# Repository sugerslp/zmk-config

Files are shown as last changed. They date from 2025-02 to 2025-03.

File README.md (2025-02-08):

# キーボードについて
キーボード名：Title72  
[Teihai70H](https://blog.alglab.net/archives/teihai70h-buildguide/)にインスパイアされて設計したオリジナルキーボードです。

## 特徴
・ZMKによる無線接続対応  
・60%日本語/英語配列  
・Choc v2スイッチを採用した薄い構造

## 販売
たぶん[booth](https://te9no.booth.pm/)で販売  

## ビルドガイド
[here](https://github.com/te9no/zmk-config-title72/blob/main/docs%2Fbuildguide.md)

## 回路図
[Github](https://github.com/te9no/zmk-config-title72/tree/main/kicad_data_Title72)  

## ファームウェア
[Github](https://github.com/te9no/zmk-config-title72/)  

## 注意事項
リポバッテリーを不適切に取り扱うと発火等の危険性があります。  
接続時の極性の向きや、リード線の短絡、組み立てには十分ご注意下さい。  
またPCBやケースの角、ピンヘッダーなど鋭利な箇所が多数存在していますので、怪我しないようご注意下さい。  
マイコン裏のパッドはバッテリーに接続されてるため、短絡させないようご注意下さい。  
取り扱いの不備により発生した怪我、事故等の責任は負いかねます。

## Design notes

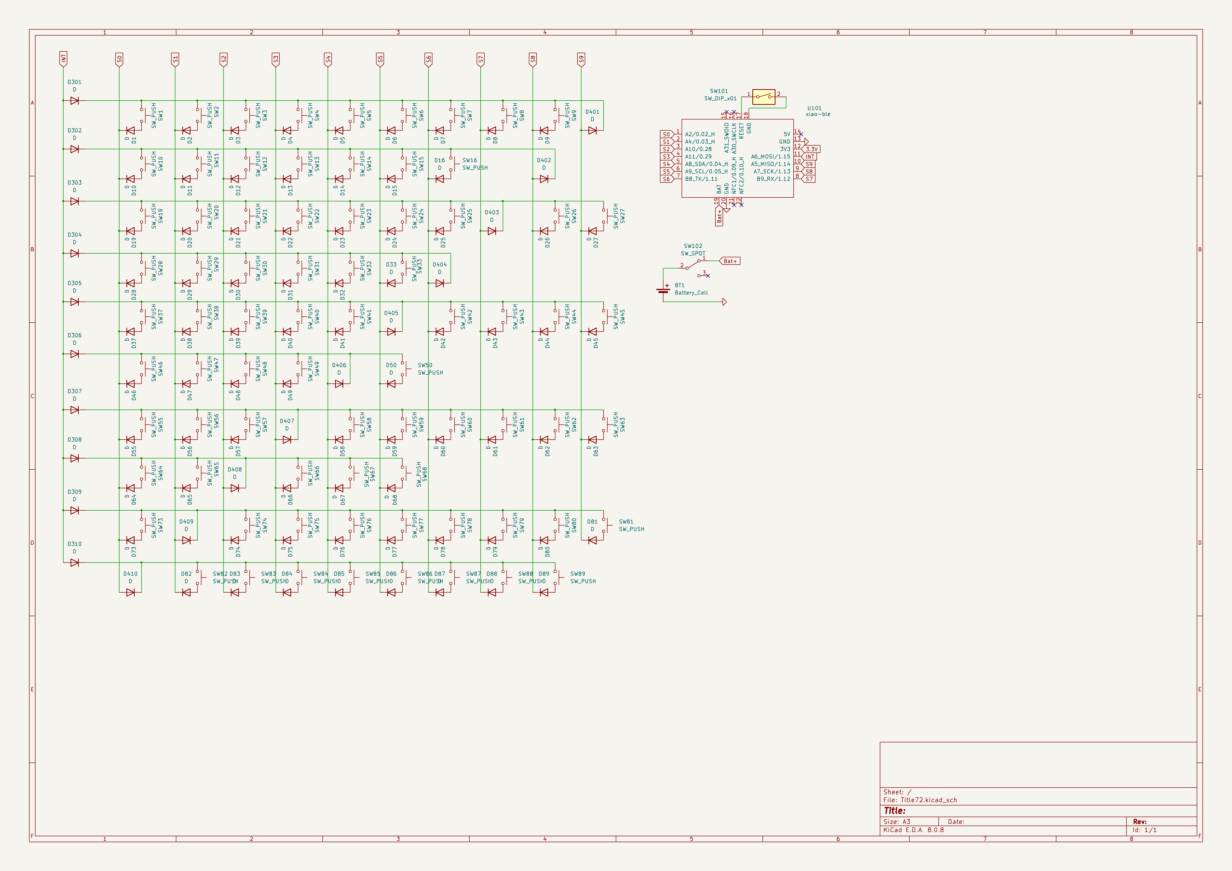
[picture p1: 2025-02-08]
kicad_data_Title72/Schematics.png

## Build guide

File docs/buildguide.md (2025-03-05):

# ビルドガイド
## 部品確認
### 付属品
|名前|数|備考|
|:-|:-|:-|
|メインPCB|x1| |
|Seeed Studio XIAO nRF52840|x1|メインPCBに取付済み|
|バッテリー用ケーブル|x1|※無線化する場合のみ|
|スイッチプレート（左）|x1| |
|スイッチプレート（右）|x1| |
|ケース（左）|x1| |
|ケース（右）|x1| |
|M3x5mmネジ|x16| |
|M3x5mmスペーサー|x8| |
|M3x1.8mmスペーサー|x8|※一部キットのみ|
 
### 別途用意するもの
|名前|数|備考|
|:-|:-|:-|
|Choc V2キースイッチ|x72| |
|Choc V2キーソケット|x72| |
|キーキャップ（日本語配列 or 英語配列）| | |
|3.7V電池（Lipoバッテリー想定）|x1|※無線化する場合のみ|
|両面テープ|x1| |

## スイッチソケット（PCBマウントスタビライザー）の実装
ソケットは日本語配列と英語配列で使用するキーに注意しながらはんだ付けする。  
 
## バッテリーケーブルの実装
メイン基板を裏向きにして、バッテリーのパッドに＋－を間違えないようにしてケーブルを差し込む。  
※上が+（VCC、赤）、下が-（GND、黒）  
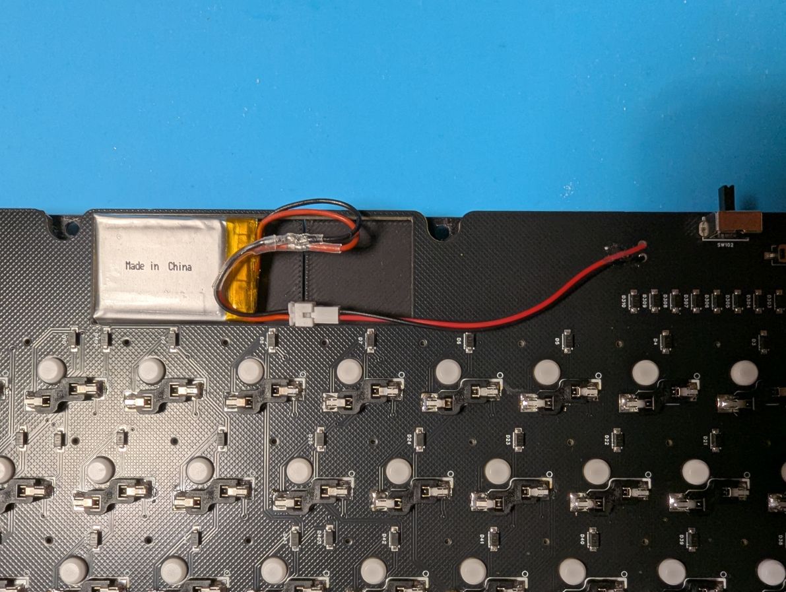
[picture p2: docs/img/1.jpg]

表からはんだ付けする。  
はんだ付け後、裏面に伸びたリード線はショートしないようにカットする。  
バッテリーケーブルはテープや接着剤でPCBに固定することを推奨。  

## バッテリーの実装
PCB上部中央の空間に収まるようにバッテリーを両面テープなどで固定する。  
※ケーブルのコネクタも空間に収まるように調整すること。 
バッテリーケーブルとバッテリーを接続する。（赤線と赤線、黒線と黒線がつながるようにすること。）  

## スイッチプレートの組み立て
スイッチプレートとメインPCBを重ねてスイッチを挿していく。  
 
## ケースの組み立て
M3ネジでPCBをケースに固定する。  

## ファームウェアの書き込み
USBケーブルでPCに接続する。  
裏面のリセットスイッチを素早く2回クリックするとUSBドライブとしてマウントされる。  
UF2ファイルをドラッグ＆ドロップするとファームウェアの書き込みが始まる。  
完了すると自動的に切断され、使用できる状態となる。  
 
## レイヤー機能
|#|レイヤー|機能|
|:-|:--|:--|
|0|USレイヤー|デフォルトのレイヤー|
|1|疑似JISレイヤー|tabキー長押しで有効/無効を切り替える。|
|2|Functionレイヤー|
|3|BTレイヤー|数字1~5を押すことで接続プロファイルを切り替える。|

### JISレイヤー機能
・tabキー長押しでレイヤー1（疑似JISレイヤー）を有効/無効を切り替える。  
・レイヤー1は日本語配列として認識しているキーボードで英語配列の入力ができる。  
（例：日本語配列として認識しているPCで、レイヤー1を有効にしてSHIFT+2→＠を入力） 

### 接続プロファイル切り替え機能
・「＼」キーを押している間レイヤー3が有効になり、同時に数字1~5を押すことで接続プロファイルを切り替える。  
・レイヤー5で「`」キー→現在の接続プロファイルを消去する。tabキー→接続プロファイルを全て消去する。  
 
## その他
### 電源スイッチ
電源スイッチは左側でON、右側でOFFとなる。

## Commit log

2025-01-29 kicad data
    [Title72.kicad_sch]
2025-01-29 update for jis layout
    [Title72.kicad_sch]
2025-02-25 fix: improve clarity in build guide for battery installation instructions
2025-02-25 fix: add missing double-sided tape to build guide materials list
2025-02-25 fix: add Seeed Studio XIAO nRF52840 to build guide materials list
2025-02-27 fix: update key switch and socket names for clarity in build guide
2025-02-27 fix: add M3x1.8mm spacers to build guide materials list
2025-03-05 fix: enhance clarity in build guide for assembly instructions
